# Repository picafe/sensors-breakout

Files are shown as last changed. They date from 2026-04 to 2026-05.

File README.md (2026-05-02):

# Sensors Breakout

Small 4-layer KiCad PCB that packs a RTC and several I²C and SPI sensors into a compact board (around 3x1.5 cm) for cheap assembly, lots of config options, and testing sensors.

---

## What it is

A breakout board of the **PCF8563 RTC**, **Sensirion SHT41** temperature/humidity sensor on an I²C bus. There is a **STMicro LSM6DSV** IMU connected over SPI with a 7-pin JST SH connector, and **QST QMC6309** magnetometer connected over I²C to the LSM6DSV's sensorhub with level shifting.

1.8 V power + logic for the RTC, temp sensor, and IMU, while keeping the magnetometer at 3.3 V via a LDO and BSS138 level shifter, so the design stays compatible with economic JLC PCBA (since QMC6309 is the only precise magnetometer offered with economic PCBA).

---

## Motivation

The board started as a quick PCF8563 test board which would go on a few of my other projects, and now is a general purpose board for testing sensors, with QWIIC-style connectors (JST SH).

---

## Features

| Area | Detail |
|---|---|
| **RTC** | PCF8563 + crystal |
| **Temp/Humidity** | SHT41 (can be populated from a cheap breakout or omitted) |
| **Motion** | LSM6DSV 6-axis IMU |
| **Magnetometer** | QMC6309 |

- **Power:** 1.8 V rail for core I²C peripherals; 3.3 V LDO, VBAT input, and level shifting for magnetometer
- **Interface:** QWIIC-compatible connector; optional status LED with 3‑pad solder jumper (auto / manual pin / off)

---

## Current design

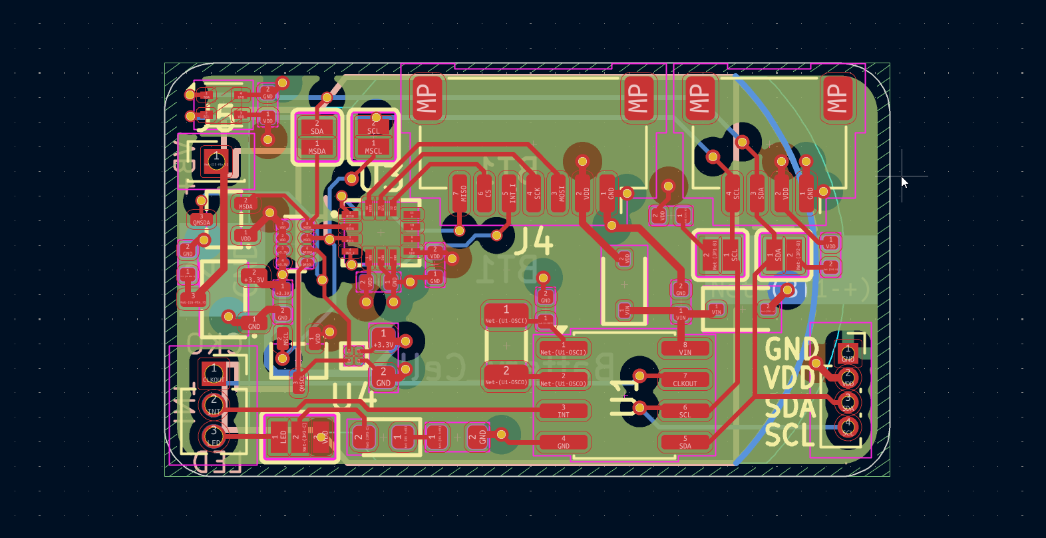
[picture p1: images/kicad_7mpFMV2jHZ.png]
PCB layout — routing


3D view:

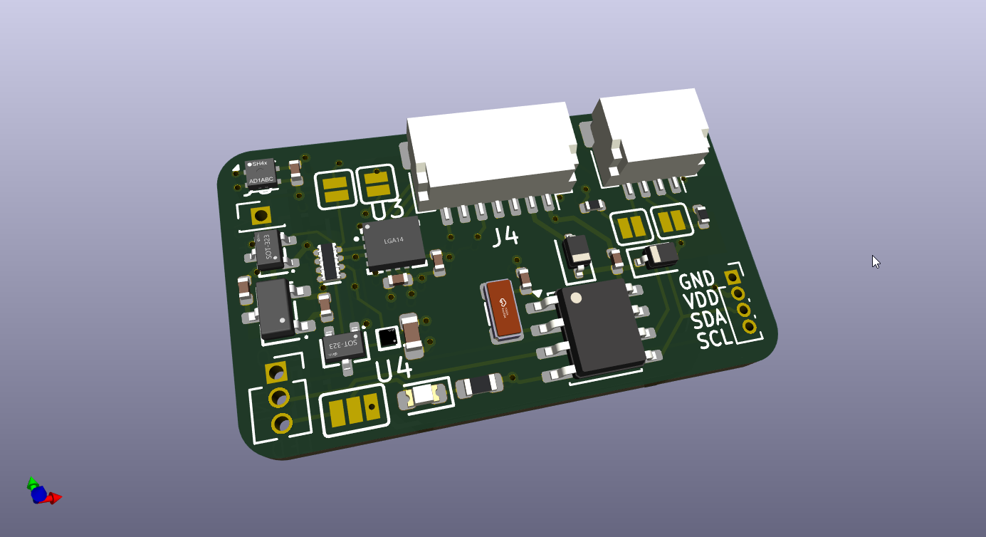
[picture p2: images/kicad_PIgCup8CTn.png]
PCB 3D view


---

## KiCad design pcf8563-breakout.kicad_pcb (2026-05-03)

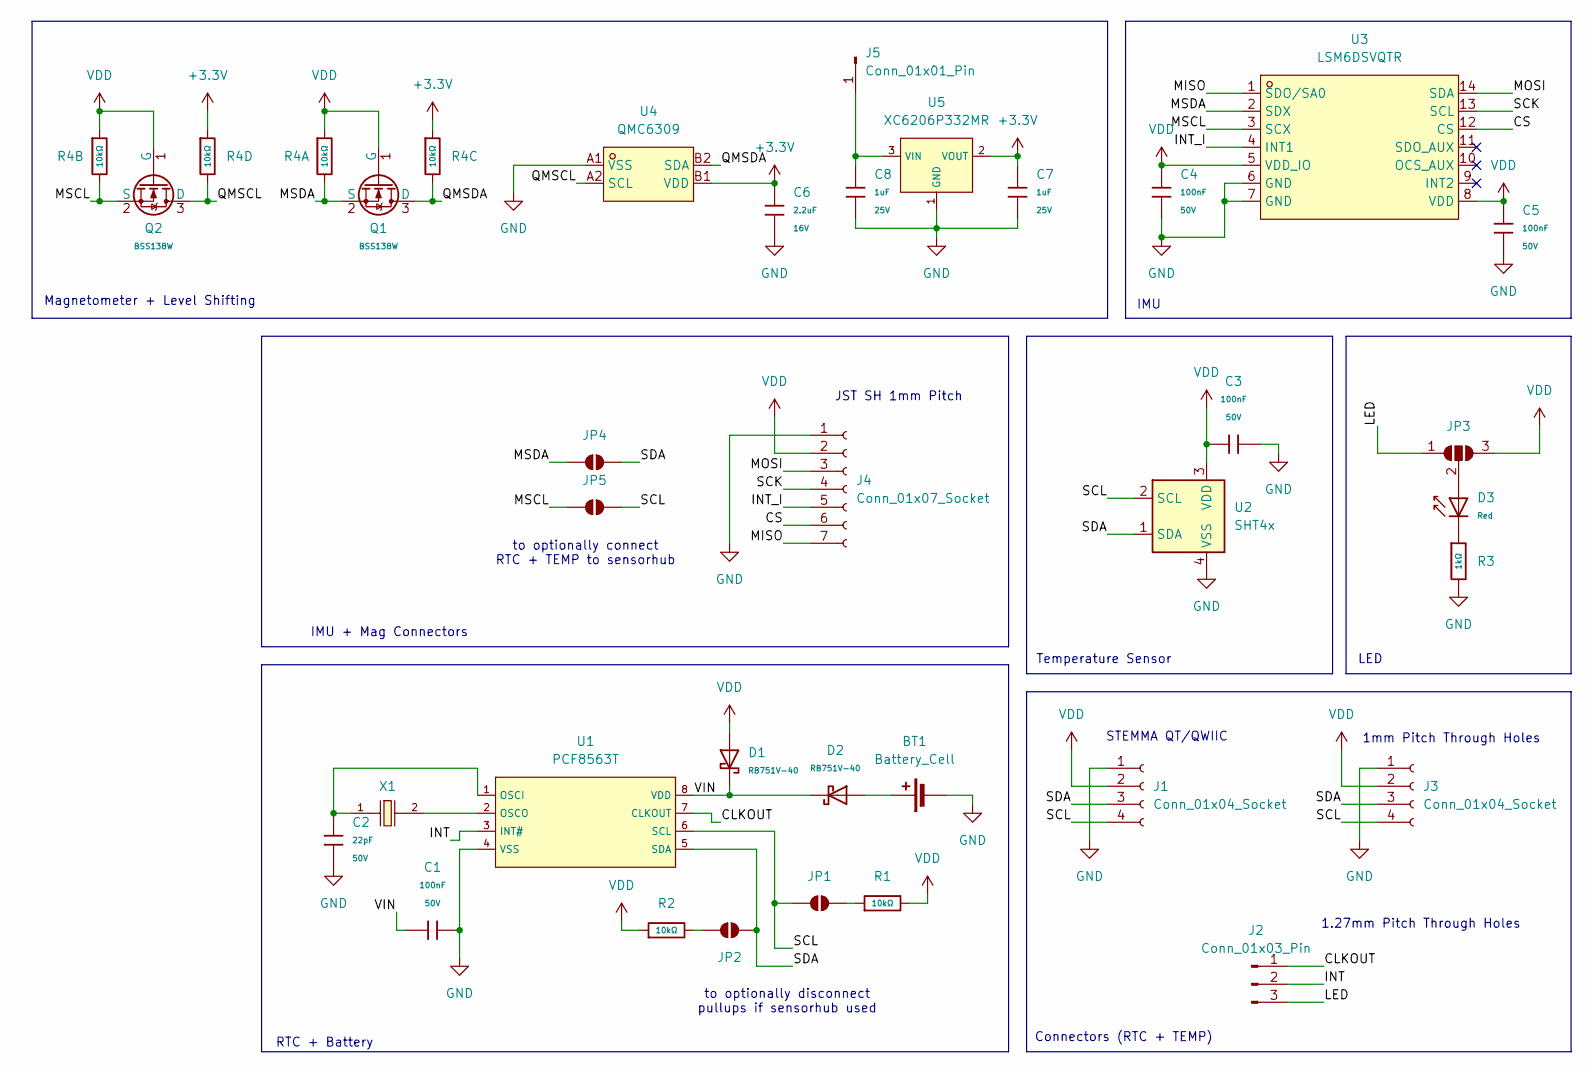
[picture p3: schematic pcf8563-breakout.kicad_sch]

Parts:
BT1: Battery_Cell; BAT-SMD_BS-CR2032-8
C1, C3, C4, C5: 100nF; C_0402; Voltage Rated 50V; Tolerance ±10%; Part CL05B104KB54PNC; LCSC C307331
C2: 22pF; C_0402; Voltage Rated 50V; Tolerance ±5%; Part 0402CG220J500NT; LCSC C1555
C6: 2.2uF; C_0603; Voltage Rated 16V; Tolerance ±10%; Part CL10A225KO8NNNC; LCSC C23630
C7, C8: 1uF; C_0402; Voltage Rated 25V; Tolerance ±10%; Part CL05A105KA5NQNC; LCSC C52923
D1, D2: RB751V-40; D_SOD-323; Forward Voltage (Vf@If) 370mV@1mA; Reverse Voltage (Vr) 40V; Part RB751V-40; LCSC C7502691
D3: Red; D_0603; Part KT-0603R; LCSC C2286
J1: Conn_01x04_Socket; JST_SH_SM04B-SRSS-TB_1x04-1MP_P1.00mm_Horizontal
J2: Conn_01x03_Pin; PinSocket_1x03_P1.27mm_Vertical
J3: Conn_01x04_Socket; PinSocket_1x04_P1.00mm_Vertical
J4: Conn_01x07_Socket; JST_SH_SM07B-SRSS-TB_1x07-1MP_P1.00mm_Horizontal
J5: Conn_01x01_Pin; PinHeader_1x01_P1.27mm_Vertical
JP1, JP2, JP4, JP5: SolderJumper_2_Open; SolderJumper-2-Sparkfun
JP3: SolderJumper_3_Open; SolderJumper-3-Sparkfun
Q1, Q2: BSS138W; Q_SOT-323; Part BSS138W; LCSC C28646265
R1, R2: 10kΩ; R_0402; Overload Voltage (Max) 50V; Tolerance ±1%; Part 0402WGF1002TCE; LCSC C25744
R3: 1kΩ; R_0603; Overload Voltage (Max) 75V; Tolerance ±1%; Part 0603WAF1001T5E; LCSC C21190
R4: 10kΩ; R_0402x4; Tolerance ±5%; Part 4D02WGJ0103TCE; LCSC C25725
U1: PCF8563T; SOIC-8_3.9x4.9mm_P1.27mm; Operating Voltage 1V~5.5V; Part PCF8563T/5,518; LCSC C7440
U2: SHT4x; Sensirion_DFN-4_1.5x1.5mm_P0.8mm_SHT4x_NoCentralPad
U3: LSM6DSVQTR; LGA-14_L3.0-W2.5-P0.50-TL; MPN LSM6DSVTR; LCSC Part C5267399
U4: QMC6309; X1-WLB0808-4_L0.8-W0.8-P0.40-TL; MPN QMC6309; LCSC Part C5439871
U5: XC6206P332MR; SOT-23-3_L2.9-W1.6-P1.90-LS2.8-BR; Output Voltage 3.3V; Dropout Voltage 680mV@(100mA); Part XC6206P332MR-G; LCSC C5446
X1: Q13FC1350000400; FC-135R_L3.2-W1.5; Frequency Tolerance ±20ppm; Part Q13FC13500004; LCSC C32346

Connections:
+3.3V: C6.1, C7.1, R4.3, R4.4, U4.B1 (VDD), U5.2 (VOUT)
/CLKOUT: J2.1, U1.7 (CLKOUT)
/CS: J4.6, U3.12 (CS)
/INT: J2.2, U1.3 (INT#)
/INT_I: J4.5, U3.4 (INT1)
/LED: J2.3, JP3.1 (A)
/MISO: J4.7, U3.1 (SDO/SA0)
/MOSI: J4.3, U3.14 (SDA)
/MSCL: JP5.1 (A), Q2.2 (S), R4.7, U3.3 (SCX)
/MSDA: JP4.1 (A), Q1.2 (S), R4.8, U3.2 (SDX)
/QMSCL: Q2.3 (D), R4.5, U4.A2 (SCL)
/QMSDA: Q1.3 (D), R4.6, U4.B2 (SDA)
/SCK: J4.4, U3.13 (SCL)
/SCL: J1.4, J3.4, JP1.1 (A), JP5.2 (B), U1.6 (SCL), U2.2 (SCL)
/SDA: J1.3, J3.3, JP2.1 (A), JP4.2 (B), U1.5 (SDA), U2.1 (SDA)
/VIN: C1.1, D1.1, D2.1, U1.8 (VDD)
GND: BT1.2 (-), C1.2, C2.2, C3.2, C4.1, C5.1, C6.2, C7.2, C8.2, J1.1, J3.1, J4.1, R3.2, U1.4 (VSS), U2.4 (VSS), U3.6 (GND), U3.7 (GND), U4.A1 (VSS), U5.1 (GND)
unnamed: BT1.1 (+), D2.2
unnamed: D3.1, R3.1
unnamed: C8.1, J5.1, U5.3 (VIN)
unnamed: JP1.2 (B), R1.1
unnamed: JP2.2 (B), R2.2
unnamed: D3.2, JP3.2 (C)
unnamed: C2.1, U1.1 (OSCI), X1.1
unnamed: U1.2 (OSCO), X1.2
VDD: C3.1, C4.2, C5.2, D1.2, J1.2, J3.2, J4.2, JP3.3 (B), Q1.1 (G), Q2.1 (G), R1.2, R2.1, R4.1, R4.2, U2.3 (VDD), U3.5 (VDD_IO), U3.8 (VDD)

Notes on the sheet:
Connectors (RTC + TEMP)
Temperature Sensor
to optionally connect RTC + TEMP to sensorhub
IMU
to optionally disconnect pullups if sensorhub used
JST SH 1mm Pitch
1mm Pitch Through Holes
IMU + Mag Connectors
RTC + Battery
1.27mm Pitch Through Holes
STEMMA QT/QWIIC
Magnetometer + Level Shifting
LED

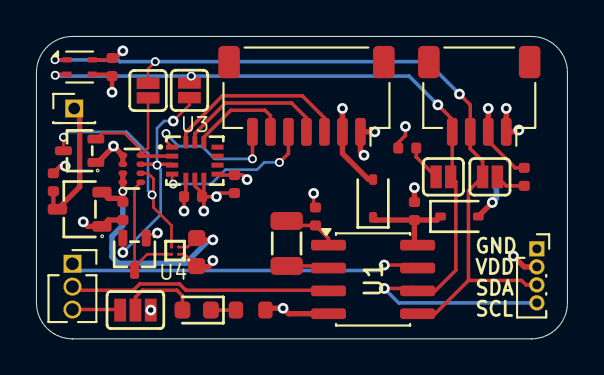
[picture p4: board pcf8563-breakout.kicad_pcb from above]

Board: 4 copper layers, 29.5 x 16.8 mm, 34 parts (1 on the bottom side), 26 nets.

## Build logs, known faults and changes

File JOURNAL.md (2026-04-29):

---
Title: Sensors Breakout
Author : Surya T
Description : Breakout board for PCF8563 RTC, SHT41, LSM6DSV IMU, QMC6309 magnetometer in a tiny package
Created On: 04/14/2026
---

# 04-14-2026 — Starting PCF8563 RTC breakout

I started the project today with the intention of making a quick breakout for the pcf8563 RTC. I was planning to use this in other projects (such as a bigger RPI hat and a clock), so I wanted to make a quick breakout board to test my layout and see how it works. Today, I spent roughly 3hrs on the project, from creating it, reading the datasheet for the pcf8563 (I had already read a portion of it before), and then designing the layout. The RTC has one internal capacitor for the 32.768kHz crystal, and one external capacitor for the 32.768kHz crystal. My overall goal for this board is to make it as small as possible and cheap with JLC basic assembly. I mostly choose the RTC becuase it is a basic component.
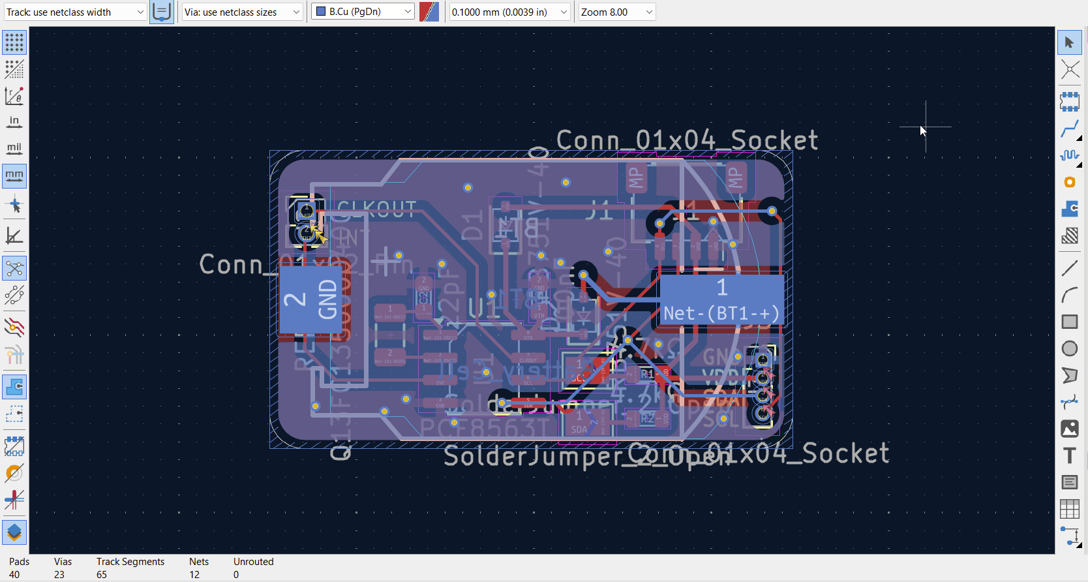
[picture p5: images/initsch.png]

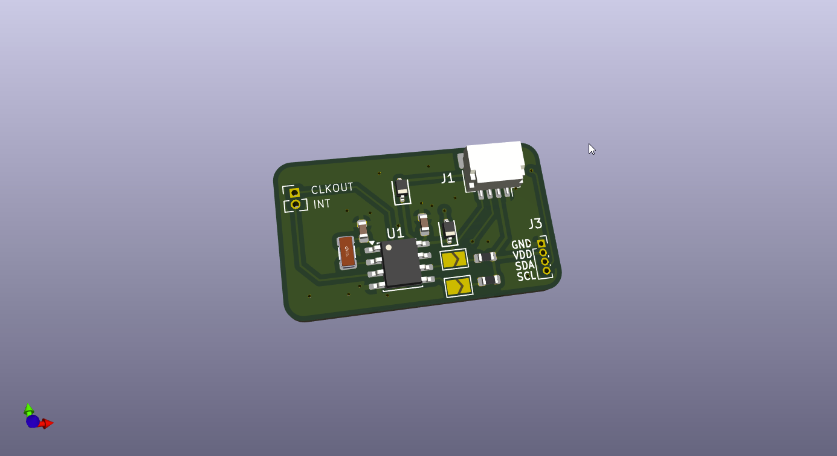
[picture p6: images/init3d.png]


`Total time spent: 3 hours`

# 04-15-2026 — SHT41, LED jumper, tighter layout

I tried to make the layout a bit more compact, and also added a few more components to the board. I originally planned this to be only QWIIC compatible with a battery holder and RTC, but I figured I could attach more components to the board if I wanted to. Since it's I2C, I first decided to add a temp sensor (SHT41). Although not on JLC, I can just buy a breakout from aliexpress for ~$2 and desolder with my reflow plate, which should be fairly doable if I'm careful. I can alo just exclude it if I want. I also decided to add an optional status LED (solder jumper); low power red LED.
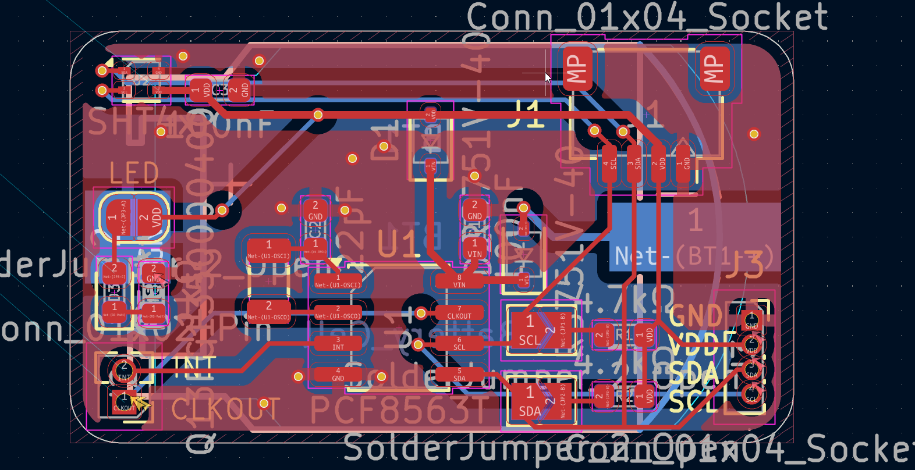
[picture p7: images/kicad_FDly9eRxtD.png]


I later decided to turn the jumper into a 3 terminal jumper and give an option for manual control with a breakout pin (either jump b/t VCC or LED pin or none).
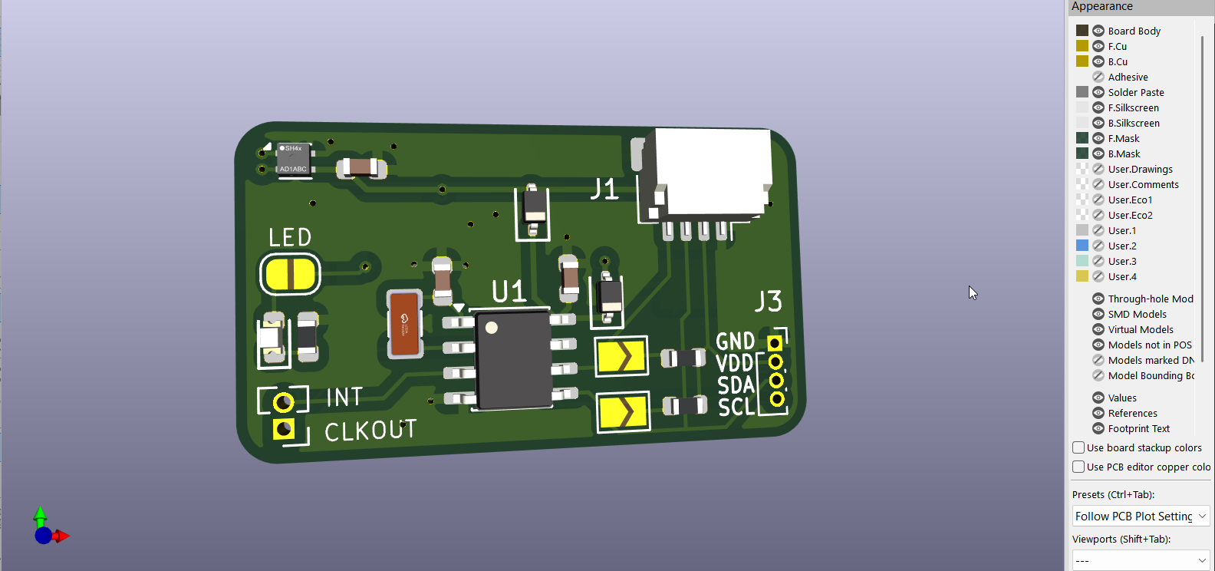
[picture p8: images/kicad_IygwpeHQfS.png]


`Total time spent: 1 hour`

# 04-17-2026 — Smaller solder jumpers and routing tweaks

I decided to switch to smaller solder jumpers. I modified a sparkfun board recently and decided to take those solder jumper footprints and modify them for my board. I also changed the layout a bit for better routing. (screenshot is before fixing routing)
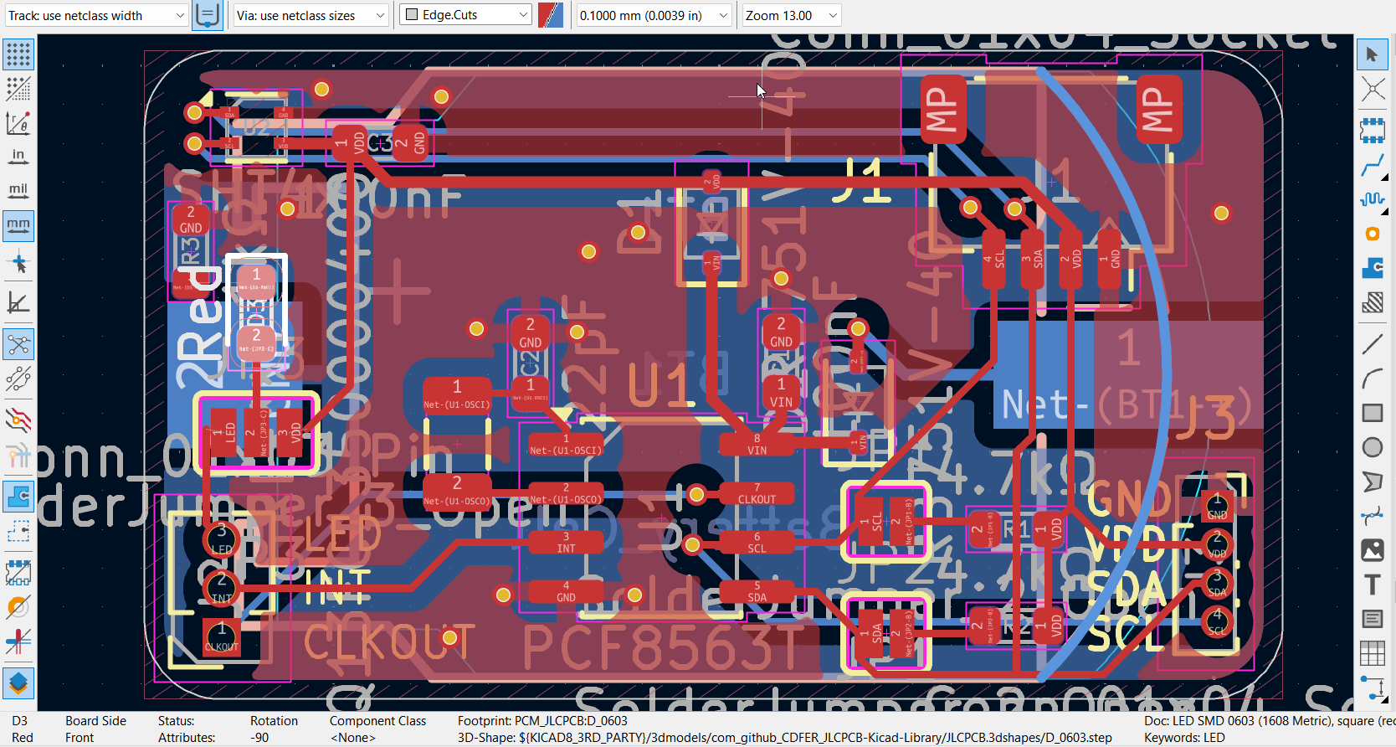
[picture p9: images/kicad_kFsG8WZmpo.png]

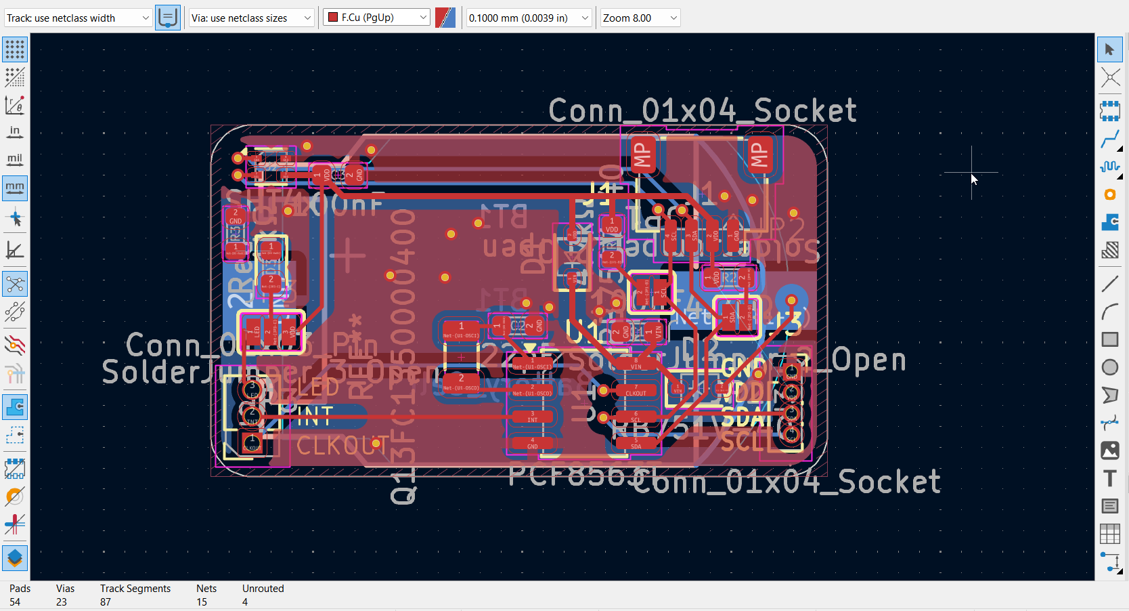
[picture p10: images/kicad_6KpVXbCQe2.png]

(yes I fixed the routing later)

`Total time spent: 1 hour`

# 04-27-2026 — SlimeVR sensors, LIS2MDL, moving to four layers

Finally post-exams and I wanted to change a bunch of the overall concept of the board. I want to eventually make a SlimeVR tracker, which is basically a NRF microcontroller, IMU, and magnetometer for full-body tracking. Although I don't have VR, I thought it could be a cool project. Commonly, the LSM6DSV is used for the IMU (since ICM45686 is not widely available anymore due to shortages), and QMC6309 for the magnetometer. However, I wanted to run my board at 1.8V for power efficiency, and the QMC6309 does not work at 1.8V ranges. I decided to use the LIS2MDL for the magnetometer instead, since it has better accuracy and can work at 1.8V power and logic. I spent some time organizing the schematic after adding the layout in and started routing. (This also meant making VDD 1.8V, which was supported by the RTC and SHT41 too).
Turns out, it was a lot more painful than initially expected. I had to change a lot of the layout to accommodate the new components. Below is my first attempt at routing.
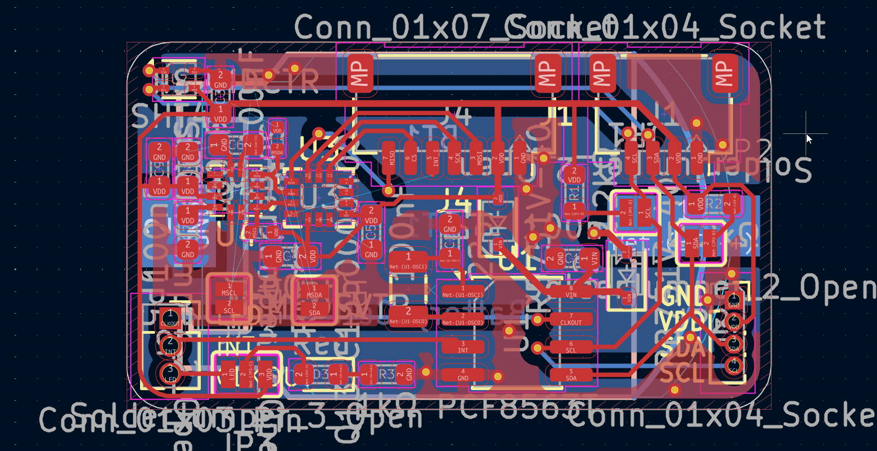
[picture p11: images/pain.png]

After realziing that this isn't ideal, I tried moving the magnetometer downwards, but this still wasn't ideal (messy routing).
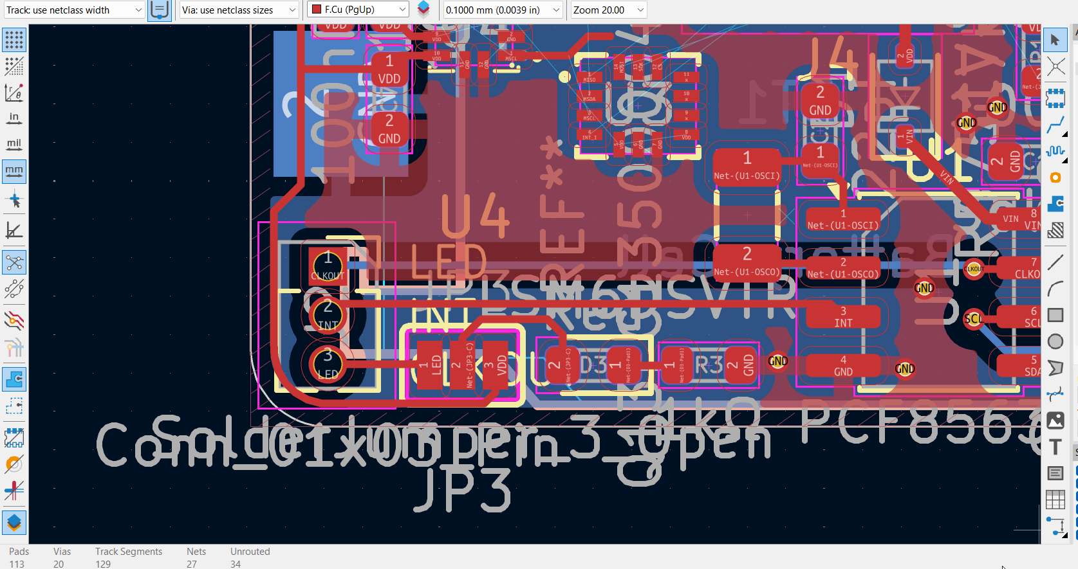
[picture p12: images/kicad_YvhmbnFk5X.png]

I had a lot of VCC traces going all over and my ground plane on the top layer almost didn't exist becuase of all the traces. Therefore, the only logical option was to switch to a 4-layer board.

`Total time spent: 2.5 hours`

# 04-28-2026 — Four-layer setup, JLC economics, QMC6309 plan

I still had to redo some of the routing since I now had a power and ground plane. This was my first time doing a 4 layer PCB, so I had to spend some time setting up the layers. My routing process (kinda) is below.
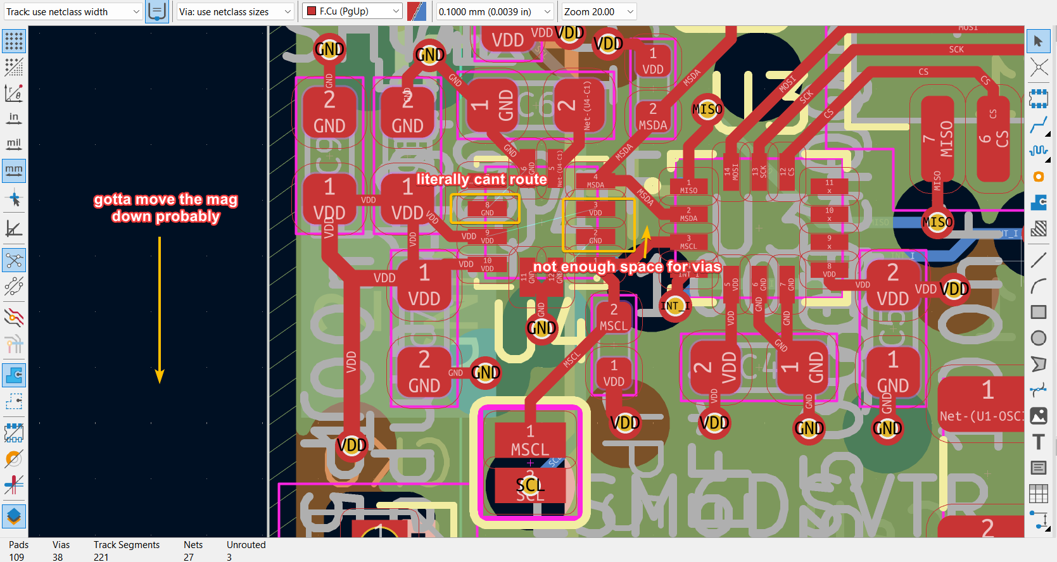
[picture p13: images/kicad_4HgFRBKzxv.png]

I eventually got something I was satisified with, and send it to someone to review. One thing I wasn't sure of is whether it was a batter practice to route nearby grounds together, or to put a via to each to the ground plane.
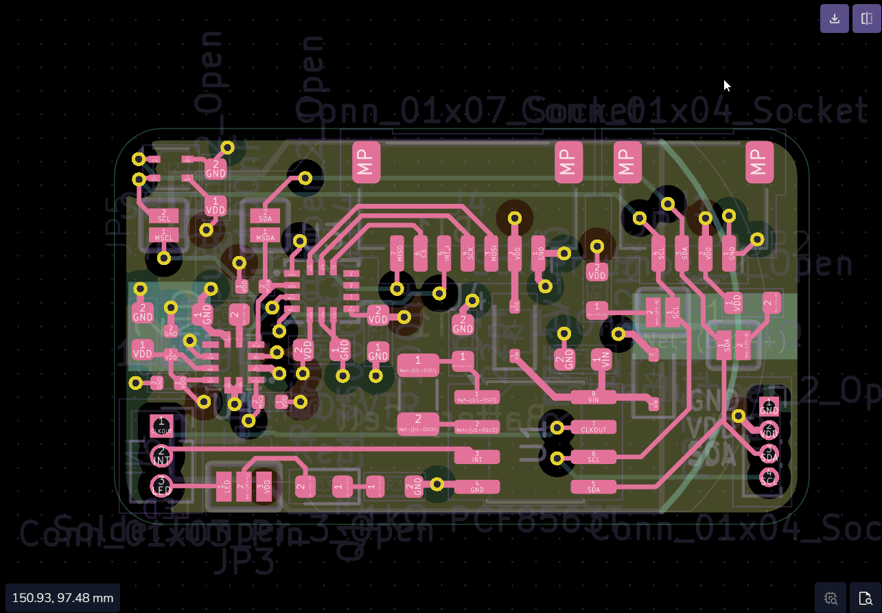
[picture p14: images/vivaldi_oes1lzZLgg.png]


HOWEVER, right after I finished and tried to upload to JLC to see the PCBA price, I found out that the magnetometer I was using (LIS2MDL) was only available for standard assembly, which brought the total cost of 2 boards to ~$115 including shipping. Since this was kinda diabolical and not what I had planned, I contemplated for a bit. I searched JLC parts for magnetometers that were available for economic assembly, and the QMC6309 was pretty much the only option. I had to switch to the QMC6309 for the magnetometer. But, I wanted it to still be compatible at 1.8V, so I then decided to add a level shifter, input for VBAT, and a 3.3V LDO (all of which are basic components so have very little cost). I decided to switch over the schematic and do the layout tomorrow.

`Total time spent: 2.5 hours`

# 04-29-2026 — Level shifter layout and shrinking passives

I first cleaned up the schematic from yesterday and then began working on the layout.
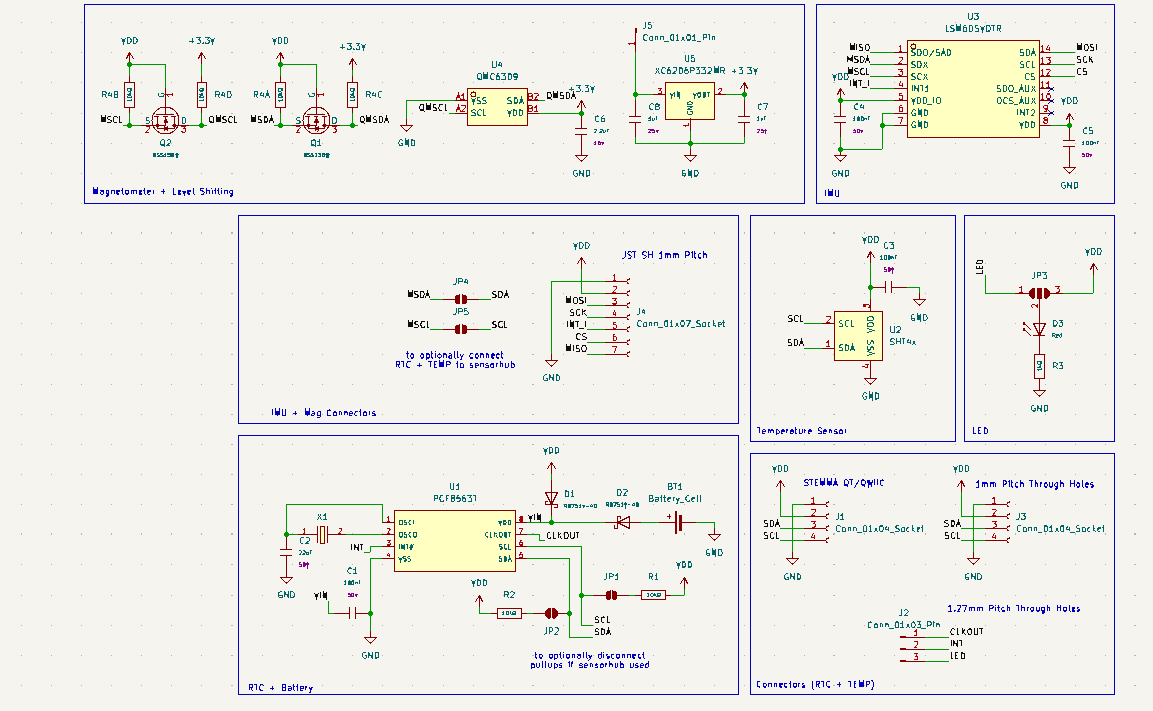
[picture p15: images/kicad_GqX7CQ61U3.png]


What I had to add, I spent quite a bit of time arranging items on the board since it was quite cramped. I also had to move the magnetometer downwards to make room for the level shifter and LDO.
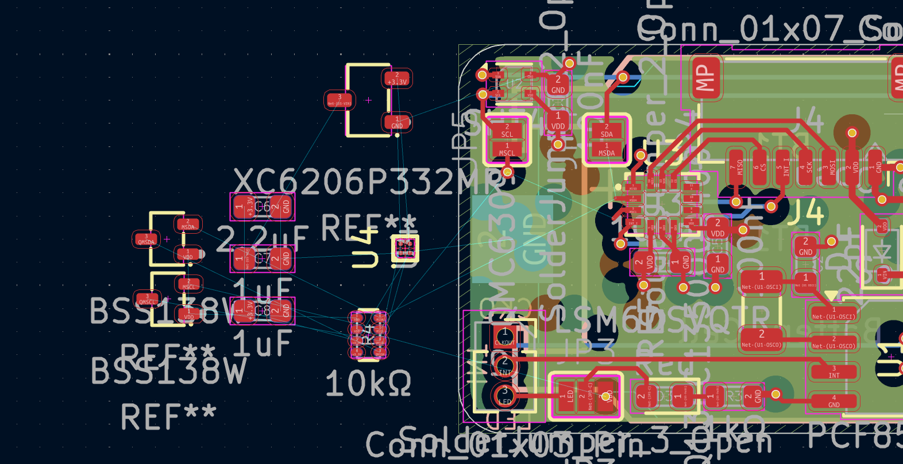
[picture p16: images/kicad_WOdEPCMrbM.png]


I had so much trouble in fact that I changed all the passives except the 2.2uF cap on the magnetometer to 0402, which finally cleared up enough space. Other than minor silkscreen conflicts, DRC was fine. I just have to get someone to review it, make adjustments, and I should be done.



`Total time spent: 2.5 hours`

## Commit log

2026-04-29 feat: updates and journal
    [pcf8563-breakout.kicad_pcb, pcf8563-breakout.kicad_sch]
2026-04-30 feat: readme
    [pcf8563-breakout.kicad_pcb]
2026-04-30 fix: readme
    [pcf8563-breakout.kicad_sch]
2026-05-03 feat: pcb fix
    [pcf8563-breakout.kicad_pcb]
